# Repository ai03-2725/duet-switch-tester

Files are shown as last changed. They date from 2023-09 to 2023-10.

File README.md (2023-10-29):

# Duet Switch Tester

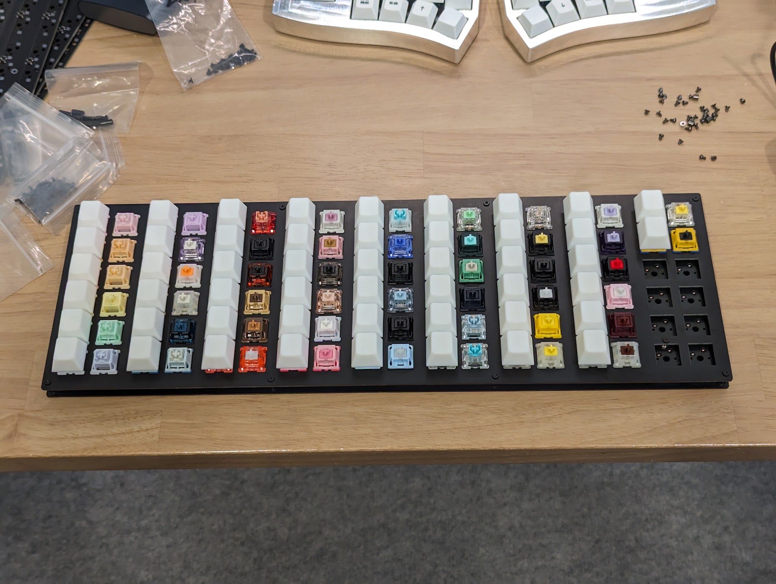
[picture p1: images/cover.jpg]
Cover image


A switch tester intended for use at events and storefronts.  
Displays two of each switch - one with a keycap for testing the keyfeel, and another without a keycap to show off the visuals.  
Can be assembled with a functioning PCB to pair the tester to a kiosk device for additional information display purposes.  

## Features
- FR4 sandwich case
- Designed to look visually balanced with the left column of each cluster having keycaps installed
- Fully hotswap PCB powered by a RP2040
- Roughly 1800-size to balance display quantity with practicality and shipping/transport constraints

## BOM
Necessary for all builds:
- 1x Plate
- 1x Bottom panel
- 8x M2x8 Spacers
- 16x M2x5 wafer-head screws
- 10x 8mm diameter rubber feet
  
Necessary if planning to pair the device to a webapp or similar:
- 1x PCB (Optional if you're not looking to pair the tester to a device)
- Optional hotswap standoffs for anchoring the PCB to the plate
    - 10x M2x3.5 Spacers
    - 20x M2x3 wafer-head screws

## Restrictions
As per the [license](https://github.com/ai03-2725/duet-switch-tester/blob/main/LICENSE), any modified version must be fully disclosed and open-sourced under the same license.  
  
There is no warranty, liability, or support for this project.  
If you intend to use this project, do so at your own risk and under your own responsibility.

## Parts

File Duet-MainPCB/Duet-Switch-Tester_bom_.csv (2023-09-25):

Component | Description | Part | References | Value | Footprint | Quantity Per PCB | Datasheet | Sim.Device | Sim.Pins
1 | Unpolarized capacitor, small symbol | C_Small | C1 C2 | 27pF | C_0402_1005Metric | 2 | ~
2 | Unpolarized capacitor, small symbol | C_Small | C3 C4 C5 C8 C9 C10 C11 C12 C13 C14 | 0.1uF | C_0402_1005Metric | 10 | ~
3 | Unpolarized capacitor, small symbol | C_Small | C6 C15 C16 C17 | 1uF | C_0402_1005Metric | 4 | ~
4 | Unpolarized capacitor, small symbol | C_Small | C7 | 10uF-OPT | C_0603_1608Metric | 1 | ~
5 | 75V 0.15A Fast Switching Diode, SOD-123 | 1N4148W | D1 D2 D3 D4 D5 D6 D7 D8 D9 D10 D11 D12 D13 D14 D15 D16 D17 D18 D19 D20 D21 D22 D23 D24 D25 D26 D27 D28 D29 D30 D31 D32 D33 D34 D35 D36 D37 D38 D39 D40 D41 D42 D43 D44 D45 D46 D47 D48 D49 D50 D51 D52 D53 D54 D55 D56 D57 D58 D59 D60 D61 D62 D63 D64 D65 D66 D67 D68 D69 D70 D71 D72 D73 D74 D75 D76 D77 D78 D79 D80 D81 D82 D83 D84 D85 D86 D87 D88 D89 D90 D91 D92 D93 D94 D95 D96 D97 D98 D99 D100 D101 D102 D103 D104 D105 D106 D107 D108 | 1N4148W | D_SOD-123-MinimalPrint | 108 | https://www.vishay.com/docs/85748/1n4148w.pdf | D | 1=K 2=A
6 | Schottky diode, small symbol | D_Schottky_Small | D109 | RB060M-60TR | D_SOD-123 | 1 | ~
7 | Resettable fuse, polymeric positive temperature coefficient, small symbol | Polyfuse_Small | F1 | 500mA | Fuse_1206_3216Metric | 1 | ~
8 | Push button switch, generic, two pins | SW_Push | K1 K2 K3 K4 K5 K6 K7 K8 K9 K10 K11 K12 K13 K14 K15 K16 K17 K18 K19 K20 K21 K22 K23 K24 K25 K26 K27 K28 K29 K30 K31 K32 K33 K34 K35 K36 K37 K38 K39 K40 K41 K42 K43 K44 K45 K46 K47 K48 K49 K50 K51 K52 K53 K54 K55 K56 K57 K58 K59 K60 K61 K62 K63 K64 K65 K66 K67 K68 K69 K70 K71 K72 K73 K74 K75 K76 K77 K78 K79 K80 K81 K82 K83 K84 K85 K86 K87 K88 K89 K90 K91 K92 K93 K94 K95 K96 K97 K98 K99 K100 K101 K102 K103 K104 K105 K106 K107 K108 | CPG151101S11-16 | MX-Hotswap-1U | 108 | ~
9 | Resistor, small symbol | R_Small | R5 R6 | 27.4 | R_0402_1005Metric | 2 | ~
10 | Resistor, small symbol | R_Small | R1 R3 R4 | 1k | R_0402_1005Metric | 3 | ~
11 | Resistor, small symbol | R_Small | R9 R10 | 5k1 | R_0603_1608Metric | 2 | ~
12 | Resistor, small symbol | R_Small | R7 R8 | 100k | R_0603_1608Metric | 2 | ~
13 | Resistor, small symbol | R_Small | R2 | 10k-OPT | R_0402_1005Metric | 1 | ~
14 | Push button switch, generic, two pins | SW_Push | SW1 SW2 | SW_Push | SW_SPST_TL3342 | 2 | ~
15 | 250mA Low Quiscent Current LDO, 3.0V output, SOT-23 | MCP1700-3002E_SOT23 | U4 | AP7313-33SRG-7 | SOT-23 | 1 | http://ww1.microchip.com/downloads/en/DeviceDoc/20001826D.pdf
16 |  | PRTR5V0U2X | U2 | PRTR5V0U2X | SOT143B | 1
17 |  | RP2040 | U3 | RP2040 | RP2040-QFN-56 | 1
18 | 32Mb Serial Flash Memory, Standard/Dual/Quad SPI, SOIC-8 | W25Q32JVSS | U1 | ZD25Q80BNIGR | USON-8-1.5mm | 1 | http://www.winbond.com/resource-files/w25q32jv%20revg%2003272018%20plus.pdf
19 |  | HRO-TYPE-C-31-M-12 | USB1 | HRO-TYPE-C-31-M-12 | HRO-TYPE-C-31-M-12-Assembly | 1
20 | Four pin crystal, GND on pins 2 and 4 | Crystal_GND24 | Y1 | 12MHz | Crystal_SMD_3225-4Pin_3.2x2.5mm | 1 | ~
Component Groups: | 20
Component Count: | 253
Fitted Components: | 253
Number of PCBs: | 1
Total components: | 253
Schematic Version:
Schematic Date:
PCB Variant: | default
BoM Date: | 9/25/2023 11:44:36 AM
Schematic Source: | Duet-Switch-Tester.kicad_sch
KiCad Version: | Eeschema 7.0.7

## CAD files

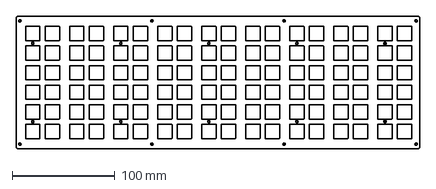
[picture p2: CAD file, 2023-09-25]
DXF/Duet Plate.dxf
392.7 x 128.9 mm

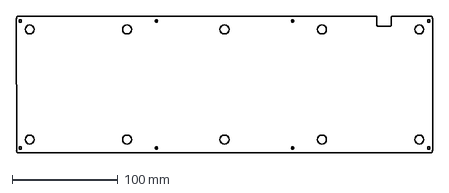
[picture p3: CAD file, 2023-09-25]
DXF/Duet Bottom.dxf
392.7 x 128.9 mm

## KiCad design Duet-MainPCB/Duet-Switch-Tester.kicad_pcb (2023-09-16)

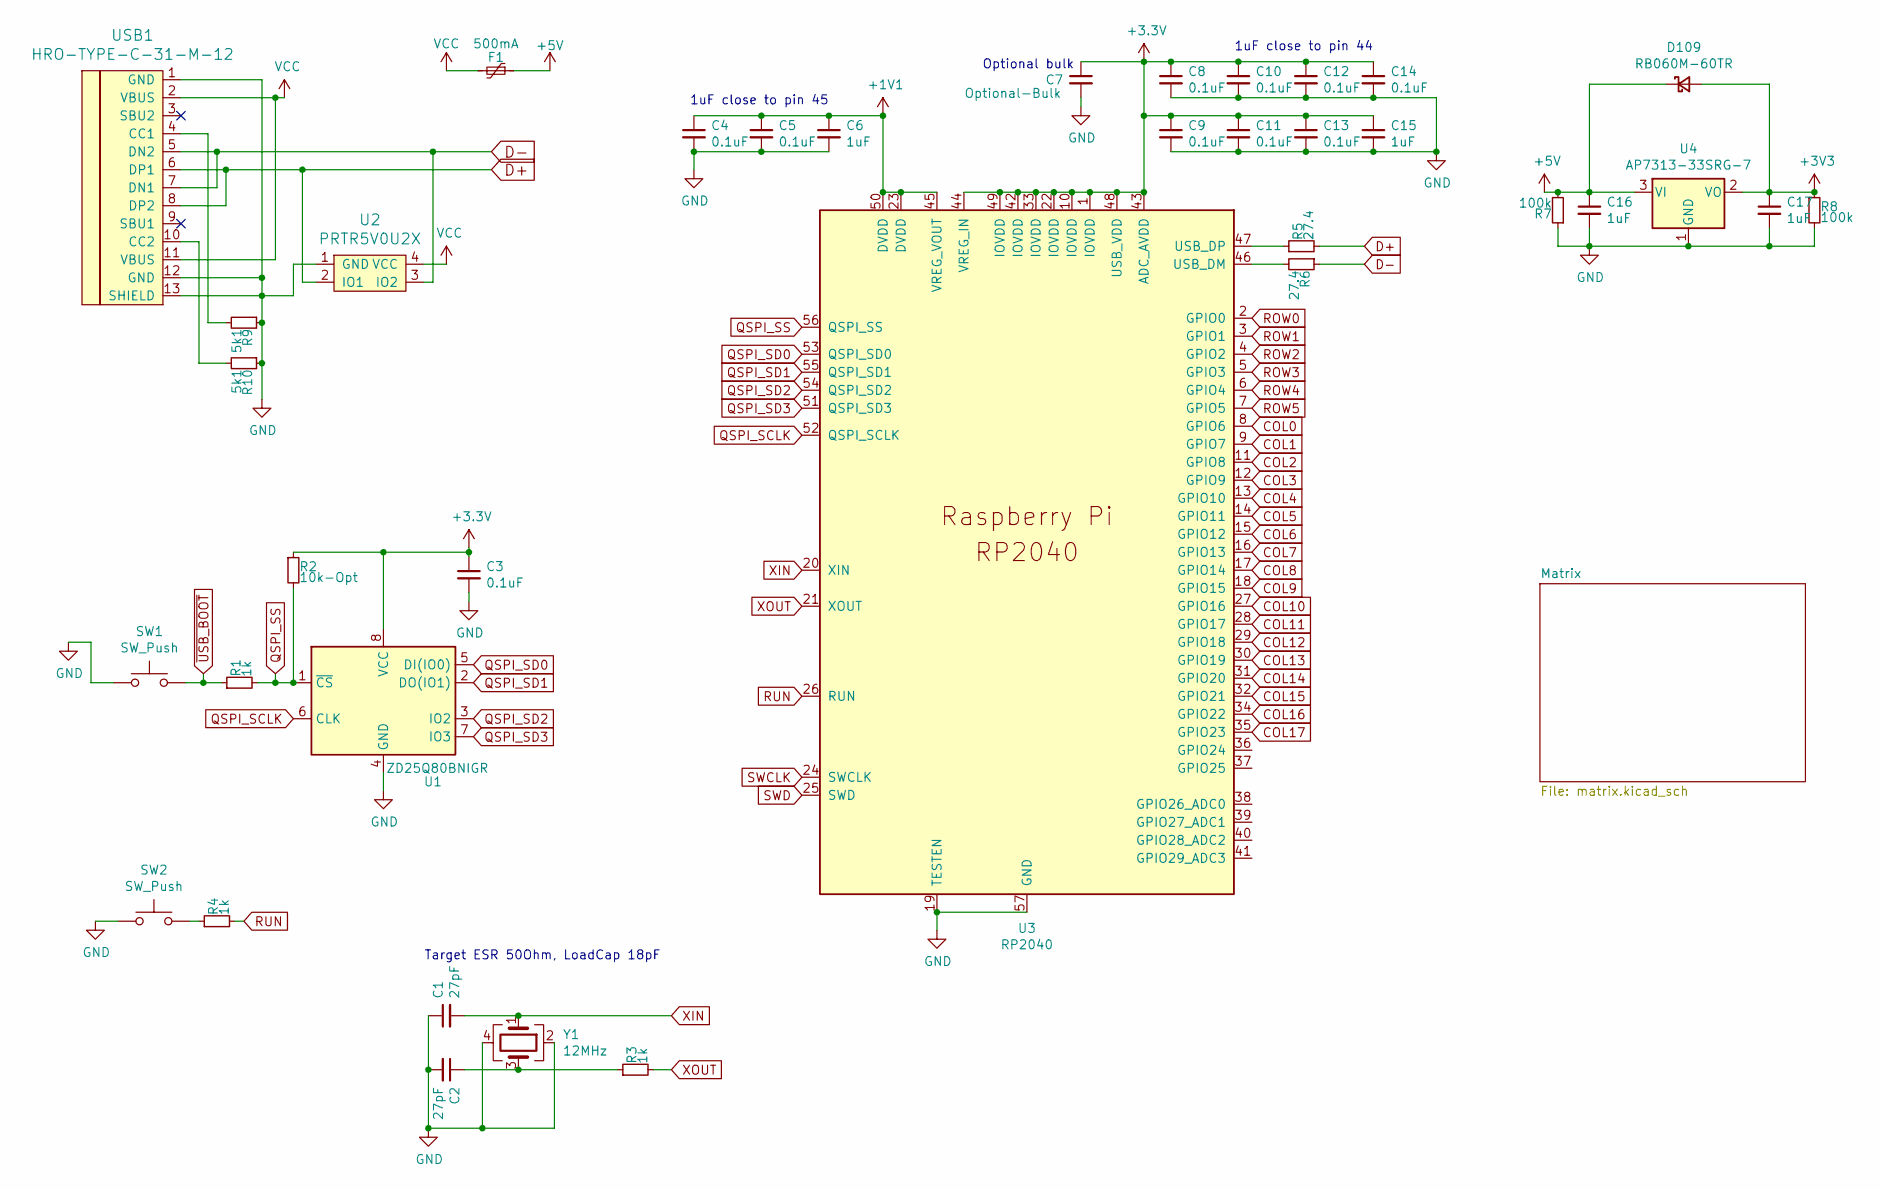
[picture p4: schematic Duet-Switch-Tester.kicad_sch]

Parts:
C1, C2: 27pF; C_0402_1005Metric
C3, C4, C5, C8, C9, C10, C11, C12, C13, C14: 0.1uF; C_0402_1005Metric
C6, C15, C16, C17: 1uF; C_0402_1005Metric
C7: Optional-Bulk; C_0603_1608Metric
D109: RB060M-60TR; D_SOD-123
F1: 500mA; Fuse_1206_3216Metric
R1, R3, R4: 1k; R_0402_1005Metric
R2: 10k-Opt; R_0402_1005Metric
R5, R6: 27.4; R_0402_1005Metric
R7, R8: 100k; R_0603_1608Metric
R9, R10: 5k1; R_0603_1608Metric
SW1, SW2: SW_Push; SW_SPST_TL3342
U1: ZD25Q80BNIGR; USON-8-1.5mm
U2: PRTR5V0U2X; SOT143B
U3: RP2040; RP2040-QFN-56
U4: AP7313-33SRG-7; SOT-23
USB1: HRO-TYPE-C-31-M-12; HRO-TYPE-C-31-M-12-Assembly
Y1: 12MHz; Crystal_SMD_3225-4Pin_3.2x2.5mm

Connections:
+1V1: C4.1, C5.1, C6.1, U3.23 (DVDD), U3.45 (VREG_VOUT), U3.50 (DVDD)
+5V: C16.1, D109.1 (K), F1.1, R7.2, U4.3 (VI)
COL0: U3.8 (GPIO6); also elsewhere on the board
COL1: U3.9 (GPIO7); also elsewhere on the board
COL2: U3.11 (GPIO8); also elsewhere on the board
COL3: U3.12 (GPIO9); also elsewhere on the board
COL4: U3.13 (GPIO10); also elsewhere on the board
COL5: U3.14 (GPIO11); also elsewhere on the board
COL6: U3.15 (GPIO12); also elsewhere on the board
COL7: U3.16 (GPIO13); also elsewhere on the board
COL8: U3.17 (GPIO14); also elsewhere on the board
COL9: U3.18 (GPIO15); also elsewhere on the board
COL10: U3.27 (GPIO16); also elsewhere on the board
COL11: U3.28 (GPIO17); also elsewhere on the board
COL12: U3.29 (GPIO18); also elsewhere on the board
COL13: U3.30 (GPIO19); also elsewhere on the board
COL14: U3.31 (GPIO20); also elsewhere on the board
COL15: U3.32 (GPIO21); also elsewhere on the board
COL16: U3.34 (GPIO22); also elsewhere on the board
COL17: U3.35 (GPIO23); also elsewhere on the board
D+: R5.2, U2.2 (IO1), USB1.6 (DP1), USB1.8 (DP2)
D-: R6.1, U2.3 (IO2), USB1.5 (DN2), USB1.7 (DN1)
GND: C1.1, C2.2, C3.2, C4.2, C5.2, C6.2, C7.2, C8.2, C9.2, C10.2, C11.2, C12.2, C13.2, C14.2, C15.2, C16.2, C17.2, R7.1, R8.2, R9.1, R10.1, SW1.1, SW2.1, U1.4 (GND), U2.1 (GND), U3.19 (TESTEN), U3.57 (GND), U4.1 (GND), USB1.1 (GND), USB1.12 (GND), USB1.13 (SHIELD), Y1.2, Y1.4
unnamed: C2.1, R3.1, Y1.3
unnamed: R4.1, SW2.2
unnamed: R6.2, U3.46 (USB_DM)
unnamed: R5.1, U3.47 (USB_DP)
unnamed: R9.2, USB1.4 (CC1)
unnamed: R10.2, USB1.10 (CC2)
QSPI_SCLK: U1.6 (CLK), U3.52 (QSPI_SCLK)
QSPI_SD0: U1.5 (DI(IO0)), U3.53 (QSPI_SD0)
QSPI_SD1: U1.2 (DO(IO1)), U3.55 (QSPI_SD1)
QSPI_SD2: U1.3 (IO2), U3.54 (QSPI_SD2)
QSPI_SD3: U1.7 (IO3), U3.51 (QSPI_SD3)
QSPI_SS: R1.2, R2.2, U1.1 (~CS), U3.56 (QSPI_SS)
ROW0: U3.2 (GPIO0); also elsewhere on the board
ROW1: U3.3 (GPIO1); also elsewhere on the board
ROW2: U3.4 (GPIO2); also elsewhere on the board
ROW3: U3.5 (GPIO3); also elsewhere on the board
ROW4: U3.6 (GPIO4); also elsewhere on the board
ROW5: U3.7 (GPIO5); also elsewhere on the board
RUN: R4.2, U3.26 (RUN)
SWCLK: U3.24 (SWCLK)
SWD: U3.25 (SWD)
VCC: F1.2, U2.4 (VCC), USB1.2 (VBUS), USB1.11 (VBUS)
XIN: C1.2, U3.20 (XIN), Y1.1
XOUT: R3.2, U3.21 (XOUT)
~USB_BOOT: R1.1, SW1.2

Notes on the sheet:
Target ESR 50Ohm, LoadCap 18pF
Optional bulk
1uF close to pin 44
1uF close to pin 45

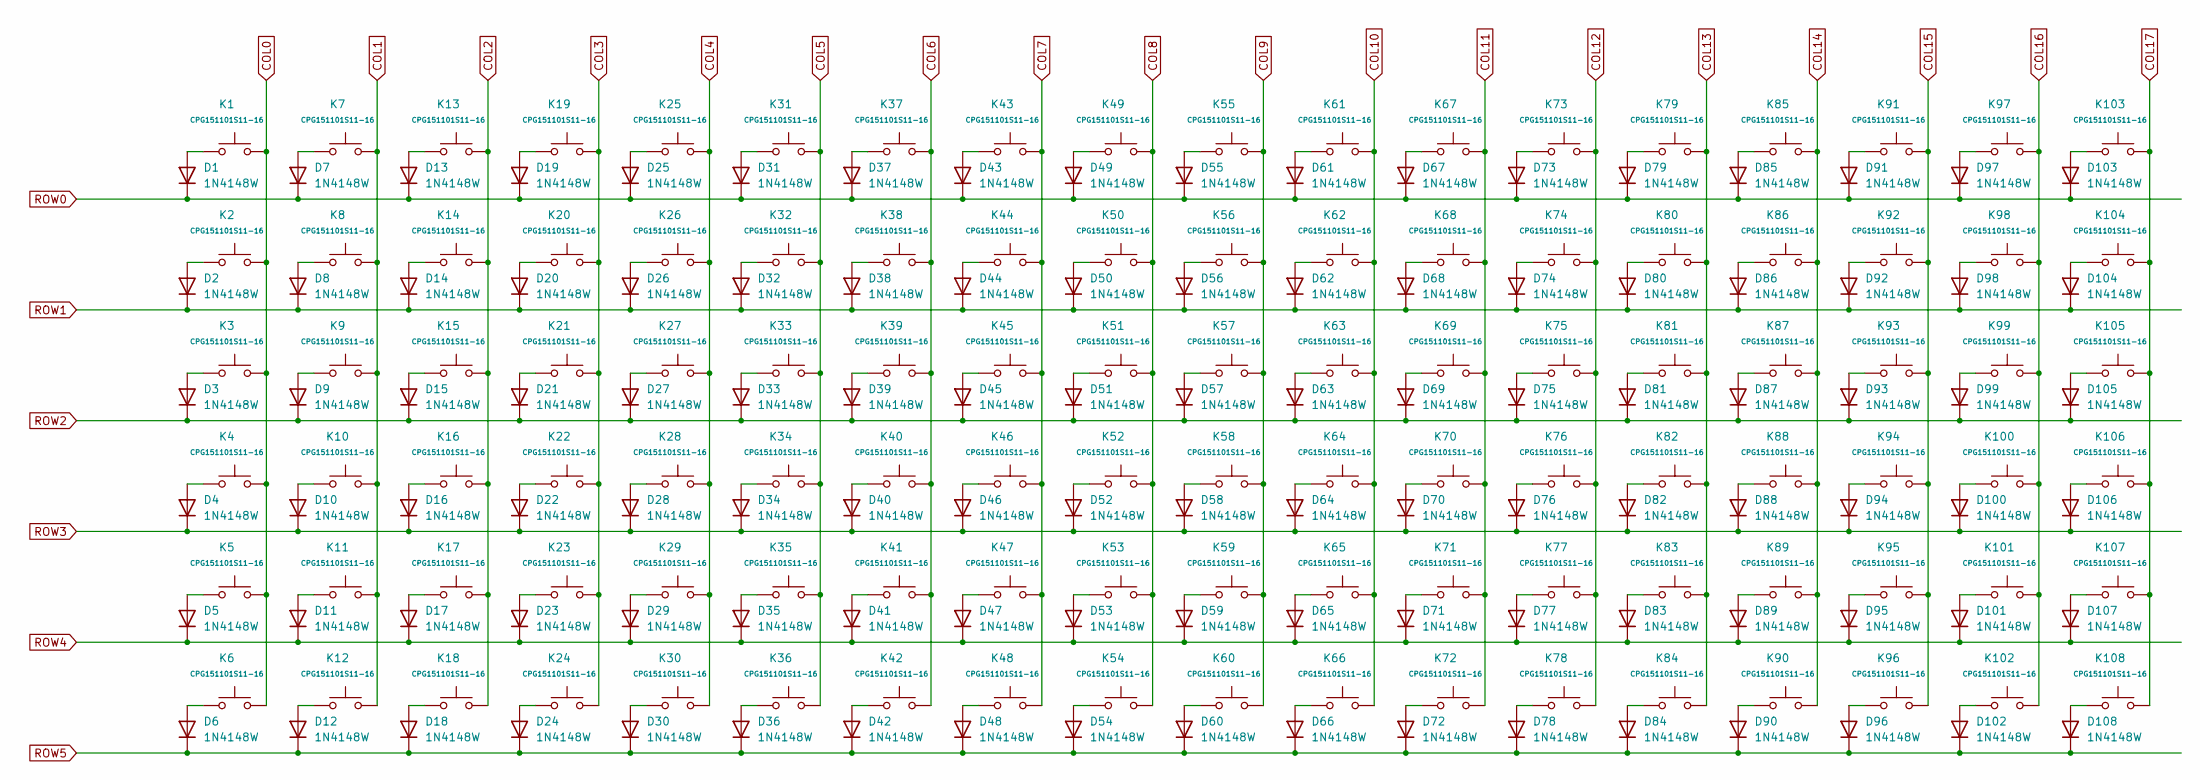
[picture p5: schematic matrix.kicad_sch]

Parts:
D1, D2, D3, D4, D5, D6, D7, D8, D9, D10, D11, D12, D13, D14, D15, D16, D17, D18, D19, D20, D21, D22, D23, D24, D25, D26, D27, D28, D29, D30, D31, D32, D33, D34, D35, D36, D37, D38, D39, D40, D41, D42, D43, D44, D45, D46, D47, D48, D49, D50, D51, D52, D53, D54, D55, D56, D57, D58, D59, D60, D61, D62, D63, D64, D65, D66, D67, D68, D69, D70, D71, D72, D73, D74, D75, D76, D77, D78, D79, D80, D81, D82, D83, D84, D85, D86, D87, D88, D89, D90, D91, D92, D93, D94, D95, D96, D97, D98, D99, D100, D101, D102, D103, D104, D105, D106, D107, D108: 1N4148W; D_SOD-123
K1, K2, K3, K4, K5, K6, K7, K8, K9, K10, K11, K12, K13, K14, K15, K16, K17, K18, K19, K20, K21, K22, K23, K24, K25, K26, K27, K28, K29, K30, K31, K32, K33, K34, K35, K36, K37, K38, K39, K40, K41, K42, K43, K44, K45, K46, K47, K48, K49, K50, K51, K52, K53, K54, K55, K56, K57, K58, K59, K60, K61, K62, K63, K64, K65, K66, K67, K68, K69, K70, K71, K72, K73, K74, K75, K76, K77, K78, K79, K80, K81, K82, K83, K84, K85, K86, K87, K88, K89, K90, K91, K92, K93, K94, K95, K96, K97, K98, K99, K100, K101, K102, K103, K104, K105, K106, K107, K108: CPG151101S11-16; MX-Hotswap-1U

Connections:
COL0: K1.2, K2.2, K3.2, K4.2, K5.2, K6.2; also elsewhere on the board
COL1: K7.2, K8.2, K9.2, K10.2, K11.2, K12.2; also elsewhere on the board
COL2: K13.2, K14.2, K15.2, K16.2, K17.2, K18.2; also elsewhere on the board
COL3: K19.2, K20.2, K21.2, K22.2, K23.2, K24.2; also elsewhere on the board
COL4: K25.2, K26.2, K27.2, K28.2, K29.2, K30.2; also elsewhere on the board
COL5: K31.2, K32.2, K33.2, K34.2, K35.2, K36.2; also elsewhere on the board
COL6: K37.2, K38.2, K39.2, K40.2, K41.2, K42.2; also elsewhere on the board
COL7: K43.2, K44.2, K45.2, K46.2, K47.2, K48.2; also elsewhere on the board
COL8: K49.2, K50.2, K51.2, K52.2, K53.2, K54.2; also elsewhere on the board
COL9: K55.2, K56.2, K57.2, K58.2, K59.2, K60.2; also elsewhere on the board
COL10: K61.2, K62.2, K63.2, K64.2, K65.2, K66.2; also elsewhere on the board
COL11: K67.2, K68.2, K69.2, K70.2, K71.2, K72.2; also elsewhere on the board
COL12: K73.2, K74.2, K75.2, K76.2, K77.2, K78.2; also elsewhere on the board
COL13: K79.2, K80.2, K81.2, K82.2, K83.2, K84.2; also elsewhere on the board
COL14: K85.2, K86.2, K87.2, K88.2, K89.2, K90.2; also elsewhere on the board
COL15: K91.2, K92.2, K93.2, K94.2, K95.2, K96.2; also elsewhere on the board
COL16: K97.2, K98.2, K99.2, K100.2, K101.2, K102.2; also elsewhere on the board
COL17: K103.2, K104.2, K105.2, K106.2, K107.2, K108.2; also elsewhere on the board
unnamed: D1.2 (A), K1.1
unnamed: D2.2 (A), K2.1
unnamed: D3.2 (A), K3.1
unnamed: D4.2 (A), K4.1
unnamed: D5.2 (A), K5.1
unnamed: D6.2 (A), K6.1
unnamed: D7.2 (A), K7.1
unnamed: D8.2 (A), K8.1
unnamed: D9.2 (A), K9.1
unnamed: D10.2 (A), K10.1
unnamed: D11.2 (A), K11.1
unnamed: D12.2 (A), K12.1
unnamed: D13.2 (A), K13.1
unnamed: D14.2 (A), K14.1
unnamed: D15.2 (A), K15.1
unnamed: D16.2 (A), K16.1
unnamed: D17.2 (A), K17.1
unnamed: D18.2 (A), K18.1
unnamed: D19.2 (A), K19.1
unnamed: D20.2 (A), K20.1
unnamed: D21.2 (A), K21.1
unnamed: D22.2 (A), K22.1
unnamed: D23.2 (A), K23.1
unnamed: D24.2 (A), K24.1
unnamed: D25.2 (A), K25.1
unnamed: D26.2 (A), K26.1
unnamed: D27.2 (A), K27.1
unnamed: D28.2 (A), K28.1
unnamed: D29.2 (A), K29.1
unnamed: D30.2 (A), K30.1
unnamed: D31.2 (A), K31.1
unnamed: D32.2 (A), K32.1
unnamed: D33.2 (A), K33.1
unnamed: D34.2 (A), K34.1
unnamed: D35.2 (A), K35.1
unnamed: D36.2 (A), K36.1
unnamed: D37.2 (A), K37.1
unnamed: D38.2 (A), K38.1
unnamed: D39.2 (A), K39.1
unnamed: D40.2 (A), K40.1
unnamed: D41.2 (A), K41.1
unnamed: D42.2 (A), K42.1
unnamed: D43.2 (A), K43.1
unnamed: D44.2 (A), K44.1
unnamed: D45.2 (A), K45.1
unnamed: D46.2 (A), K46.1
unnamed: D47.2 (A), K47.1
unnamed: D48.2 (A), K48.1
unnamed: D49.2 (A), K49.1
unnamed: D50.2 (A), K50.1
unnamed: D51.2 (A), K51.1
unnamed: D52.2 (A), K52.1
unnamed: D53.2 (A), K53.1
unnamed: D54.2 (A), K54.1
unnamed: D55.2 (A), K55.1
unnamed: D56.2 (A), K56.1
unnamed: D57.2 (A), K57.1
unnamed: D58.2 (A), K58.1
unnamed: D59.2 (A), K59.1
unnamed: D60.2 (A), K60.1
unnamed: D61.2 (A), K61.1
unnamed: D62.2 (A), K62.1
unnamed: D63.2 (A), K63.1
unnamed: D64.2 (A), K64.1
unnamed: D65.2 (A), K65.1
unnamed: D66.2 (A), K66.1
unnamed: D67.2 (A), K67.1
unnamed: D68.2 (A), K68.1
unnamed: D69.2 (A), K69.1
unnamed: D70.2 (A), K70.1
unnamed: D71.2 (A), K71.1
unnamed: D72.2 (A), K72.1
unnamed: D73.2 (A), K73.1
unnamed: D74.2 (A), K74.1
unnamed: D75.2 (A), K75.1
unnamed: D76.2 (A), K76.1
unnamed: D77.2 (A), K77.1
unnamed: D78.2 (A), K78.1
unnamed: D79.2 (A), K79.1
unnamed: D80.2 (A), K80.1
unnamed: D81.2 (A), K81.1
unnamed: D82.2 (A), K82.1
unnamed: D83.2 (A), K83.1
unnamed: D84.2 (A), K84.1
unnamed: D85.2 (A), K85.1
unnamed: D86.2 (A), K86.1
unnamed: D87.2 (A), K87.1
unnamed: D88.2 (A), K88.1
unnamed: D89.2 (A), K89.1
unnamed: D90.2 (A), K90.1
unnamed: D91.2 (A), K91.1
unnamed: D92.2 (A), K92.1
unnamed: D93.2 (A), K93.1
unnamed: D94.2 (A), K94.1
unnamed: D95.2 (A), K95.1
unnamed: D96.2 (A), K96.1
unnamed: D97.2 (A), K97.1
unnamed: D98.2 (A), K98.1
unnamed: D99.2 (A), K99.1
unnamed: D100.2 (A), K100.1
unnamed: D101.2 (A), K101.1
unnamed: D102.2 (A), K102.1
unnamed: D103.2 (A), K103.1
unnamed: D104.2 (A), K104.1
unnamed: D105.2 (A), K105.1
unnamed: D106.2 (A), K106.1
unnamed: D107.2 (A), K107.1
unnamed: D108.2 (A), K108.1
ROW0: D1.1 (K), D7.1 (K), D13.1 (K), D19.1 (K), D25.1 (K), D31.1 (K), D37.1 (K), D43.1 (K), D49.1 (K), D55.1 (K), D61.1 (K), D67.1 (K), D73.1 (K), D79.1 (K), D85.1 (K), D91.1 (K), D97.1 (K), D103.1 (K); also elsewhere on the board
ROW1: D2.1 (K), D8.1 (K), D14.1 (K), D20.1 (K), D26.1 (K), D32.1 (K), D38.1 (K), D44.1 (K), D50.1 (K), D56.1 (K), D62.1 (K), D68.1 (K), D74.1 (K), D80.1 (K), D86.1 (K), D92.1 (K), D98.1 (K), D104.1 (K); also elsewhere on the board
ROW2: D3.1 (K), D9.1 (K), D15.1 (K), D21.1 (K), D27.1 (K), D33.1 (K), D39.1 (K), D45.1 (K), D51.1 (K), D57.1 (K), D63.1 (K), D69.1 (K), D75.1 (K), D81.1 (K), D87.1 (K), D93.1 (K), D99.1 (K), D105.1 (K); also elsewhere on the board
ROW3: D4.1 (K), D10.1 (K), D16.1 (K), D22.1 (K), D28.1 (K), D34.1 (K), D40.1 (K), D46.1 (K), D52.1 (K), D58.1 (K), D64.1 (K), D70.1 (K), D76.1 (K), D82.1 (K), D88.1 (K), D94.1 (K), D100.1 (K), D106.1 (K); also elsewhere on the board
ROW4: D5.1 (K), D11.1 (K), D17.1 (K), D23.1 (K), D29.1 (K), D35.1 (K), D41.1 (K), D47.1 (K), D53.1 (K), D59.1 (K), D65.1 (K), D71.1 (K), D77.1 (K), D83.1 (K), D89.1 (K), D95.1 (K), D101.1 (K), D107.1 (K); also elsewhere on the board
ROW5: D6.1 (K), D12.1 (K), D18.1 (K), D24.1 (K), D30.1 (K), D36.1 (K), D42.1 (K), D48.1 (K), D54.1 (K), D60.1 (K), D66.1 (K), D72.1 (K), D78.1 (K), D84.1 (K), D90.1 (K), D96.1 (K), D102.1 (K), D108.1 (K); also elsewhere on the board

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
Board: 2 copper layers, 253 parts (145 on the bottom side), 155 nets, no tracks yet.

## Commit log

2023-09-16 Begin project
    [Duet-Switch-Tester.kicad_pcb, Duet-Switch-Tester.kicad_sch, matrix.kicad_sch]
2023-09-24 Route PCB
    [Duet-Switch-Tester.kicad_sch, matrix.kicad_sch]
2023-09-25 Finish PCB; add case DXF files
    [Duet Bottom.dxf, Duet Plate.dxf]
2023-09-25 Make FR4 plate data
    [Duet-Switch-Tester.kicad_pcb, Duet-Switch-Tester.kicad_sch]
2023-09-25 Make FR4 bottom data
    [Duet-Switch-Tester.kicad_pcb, Duet-Switch-Tester.kicad_sch]
2023-09-25 Make case parts prettier
    [Duet-Switch-Tester.kicad_pcb]
2023-09-25 Generate production data
    [Duet-Switch-Tester-B_Cu.gbl, Duet-Switch-Tester-B_Mask.gbs, Duet-Switch-Tester-B_Paste.gbp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]
2023-09-25 Make initial JLC files
    [JLCSMT_BOM.xlsx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]
2023-09-25 Improve JLC files
    [JLCSMT_BOM.xlsx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]
2023-09-25 Correct socket orientation
    [JLCSMT_CPL.xlsx]
